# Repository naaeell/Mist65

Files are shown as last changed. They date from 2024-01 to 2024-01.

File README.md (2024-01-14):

# Mist65 ⌨✨

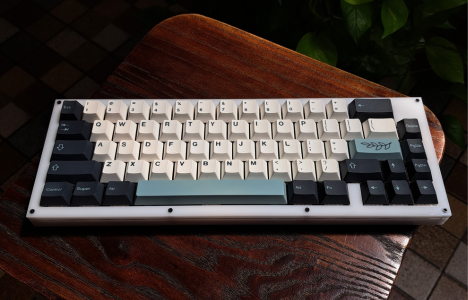
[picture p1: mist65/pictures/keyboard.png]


Introducing Mist65, a 65% custom keyboard inspired by [bakeneko65](https://github.com/kkatano/bakeneko-65). The PCB, aptly named Mist, features a sleek black design reminiscent of nighttime fog. To keep costs reasonable, the ATmega32u4 controller has been replaced with the budget-friendly RP2040 Zero, maintaining similar functionality.

Designed with a 65% layout, Mist65 strikes a balance between compactness and functionality, housing arrow keys for enhanced usability. VIA support ensures seamless keymap customization to tailor the keyboard to your preferences.

For those interested, the Mist65 PCB is available for purchase [here](https://tokopedia.link/6WUgB6gHmGb) (indonesian domestic). If considering group buy or commercial use, kindly adhere to the specified terms.

For more details about materials, instructions, and other information, please visit this [page](https://github.com/naaeell/Mist65/blob/main/mist65/README.md)

## Features 🔮

- No RGB: Clean and distraction-free experience without RGB lighting.
- Drag and Drop Flashing: Streamlined firmware updates with easy drag-and-drop functionality.
- Staggered Design: Comfortable and ergonomic typing experience with a staggered key layout.
- VIA Support: Extensive keymap customization through VIA support. (Keyboard definition required until VIA branch merge)
- QMK Firmware: Reliable and customizable keyboard experience powered by QMK firmware.
- Cost-Effective Components: Budget-friendly design using readily available components.
- Compact 65% Layout: Perfect balance between size and functionality with arrow keys for convenient navigation.
- RP2040 Zero Controller: Cost-effective and performance-maintaining controller readily available in the market.
- Community-Friendly: Vibrant community of keyboard enthusiasts for sharing experiences and modifications.
- Open-Source Design: Creative and adaptable with an open-source design for user contributions and personalization.

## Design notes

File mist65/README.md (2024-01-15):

## Materials

Part list
| Name | Quantity | Description |
| :---| :--- | :--- |
| `1N4148` | `66` | DO-35 (1N4148 or similar).  |
| `RP2040 Zero` | `1` | RP2040 Zero (You can use all models, but first pay attention to the pinout). |
| `Kailh hotswap socket (optional)` | `66` | if you want hotswap features and south facing switches. |
| `Mist65 PCB`  | `1` | Mist65 PCB is available for purchase [here](https://tokopedia.link/6WUgB6gHmGb).|

Case part list

| Name | Quantity | Details|
| :---| :---| :---|
| `Layer 1` | `1` | 3mm thicknes. |
| `Layer 2` | `3` | 3mm thickness. |
| `Layer 3` | `2` | 3mm thickness. |
| `Layer 4` | `1` | 1.5mm thickness. |
| `Layer 5` | `2` | 3mm thickness. |
| `bolts and nuts`| `8` | M2 size with 30mm length.|

*layer 1 is the bottom layer (in order of top).

Tools needed

| Name | Details |
| :---| :---|
| `Solder` |  Any kind of solder is suitable, but I recommend using a pointed or sharp-tipped one. |
| `Tin` | You'll need approximately 4-5 meters of tin wire. |
| `Flux` | Any type of flux is acceptable, but avoid overusing it.  |
| `Tweezers` | Opt for tweezers with a hooked shape. |
| `Nail clippers` | Any type with flat surfaces will work. |

## Let's start building

Firstly, prepare the necessary tools and materials. I will provide you with some tips and tricks. I recommend a soldering temperature of 300 to 350 degrees Celsius; please note that high temperatures can damage the PCB traces. Additionally, the soldering tip may quickly turn black. Each time you solder, ensure to clean the soldering tip thoroughly to prevent residue from sticking to the soldered joints later.

The use of nail clippers instead of cutting pliers is for precision, allowing you to trim component legs more neatly. Before soldering, apply an adequate amount of flux to the PCB. Applying too much flux can complicate cleaning later. Once everything is ready, test-fit the components in place, ensuring they match the silk screen markings on the PCB. Trim any excess component legs promptly; although it may take time, patience is crucial for satisfactory results.

Afterward, solder the components one by one, using tweezers to position them accurately. If a component is tilted, you can correct it with tweezers, but be cautious as this process involves melting the tin and adjusting the component's position. For the microcontroller, there is a ">" sign indicating pin 0 on the rp2040 zero; refer to the picture [below](https://github.com/naaeell/Mist65/blob/main/mist65/pictures/20240113_094051.jpg) for the microcontroller's position. Before soldering, verify that the component placement is correct to achieve neat soldering results.

Begin soldering slowly, ensuring not to melt too much tin; excessive tin can result in poor solder joints. Once all components are soldered, clean the PCB with isopropyl alcohol or contact cleaner.

## Flashing Firmware

- Flash the RPI2040 Zero by pressing and holding the boot button while plugging in the USB until it's detected on the computer as a new drive.

- Drag and drop or copy and paste the file with the .uf2 extension onto the drive. Wait until the keyboard is detected.

#### Unfortunately, the VIA support hasn't been merged into the branch yet. However, to use it, follow these additional steps:

- Visit [https://usevia.app/](https://usevia.app/) and navigate to the gear icon, then enable the "Show Design Tab" option.
- Once active, open the brush icon next to the gear. Click "Load" on the "Load Draft Definition" menu and input the via.json file located in the firmware folder.
- Return to the configuration menu, click on "Device Authorization," and your keyboard will appear, ready to use.

Choose "Mist65_via.uf2" for VIA support or "Mist65_default.uf2" for the default keymap without VIA support.

Create a new keymap tutorial soon!

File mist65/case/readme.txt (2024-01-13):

layer 1 milky white acrylic 3mm x 1
layer 2 milky white acrylic 3mm x 3
layer 3 milk white acrylic 3mm x 2
layer 4 clear acrylic 1.5mm x 2
layer 5 milky white acrylic 3mm x 3

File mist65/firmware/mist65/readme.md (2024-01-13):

# sixtyfive

sixtyfive

*A short description of the keyboard/project*

* Keyboard Maintainer: [naaeell](https://github.com/naaeell)
* Hardware Supported: *The PCBs, controllers supported*
* Hardware Availability: *Links to where you can find this hardware*

Make example for this keyboard (after setting up your build environment):

    make sixtyfive:default

Flashing example for this keyboard:

    make sixtyfive:default:flash

See the [build environment setup](https://docs.qmk.fm/#/getting_started_build_tools) and the [make instructions](https://docs.qmk.fm/#/getting_started_make_guide) for more information. Brand new to QMK? Start with our [Complete Newbs Guide](https://docs.qmk.fm/#/newbs).

## Bootloader

Enter the bootloader in 3 ways:

* **Bootmagic reset**: Hold down the key at (0,0) in the matrix (usually the top left key or Escape) and plug in the keyboard
* **Physical reset button**: Briefly press the button on the back of the PCB - some may have pads you must short instead
* **Keycode in layout**: Press the key mapped to `QK_BOOT` if it is available

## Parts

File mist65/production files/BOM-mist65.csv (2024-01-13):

Comment | Designator | Footprint | LCSC
1N4148 | D1,D10,D11,D12,D13,D14,D15,D16,D17,D18,D19,D2,D20,D21,D22,D23,D24,D25,D26,D27,D28,D29,D3,D30,D31,D32,D33,D34,D35,D36,D37,D38,D39,D4,D40,D41,D42,D43,D44,D45,D46,D47,D48,D49,D5,D50,D51,D52,D53,D54,D55,D56,D57,D58,D59,D6,D60,D61,D62,D63,D64,D65,D66,D7,D8,D9 | D_DO-35_SOD27_P7.62mm_Horizontal | C81598
1u | SW53 | Kailh_socket_MX_optional
1u | SW25 | Kailh_socket_MX_optional
1u | SW16 | Kailh_socket_MX_optional
1u | SW21 | Kailh_socket_MX_optional
1u | SW37 | Kailh_socket_MX_optional
1u | SW5 | Kailh_socket_MX_optional
1u | SW33 | Kailh_socket_MX_optional
1u | SW13 | Kailh_socket_MX_optional
1u | SW10 | Kailh_socket_MX_optional
1.25u | SW63 | Kailh_socket_MX_optional
1u | SW18 | Kailh_socket_MX_optional
1u | SW52 | Kailh_socket_MX_optional
1u | SW56 | Kailh_socket_MX_optional
1u | SW45 | Kailh_socket_MX_optional
1u | SW43 | Kailh_socket_MX_optional
1.25u | SW62 | Kailh_socket_MX_optional
1u | SW29 | Kailh_socket_MX
1u | SW36 | Kailh_socket_MX_optional
2.25u | SW42 | Kailh_socket_MX_optional
1u | SW27 | Kailh_socket_MX_optional
1u | SW2 | Kailh_socket_MX_optional
1u | SW35 | Kailh_socket_MX_optional
1u | SW31 | Kailh_socket_MX_optional
MX_stab | S4 | STAB_MX_2.25u
1u | SW41 | Kailh_socket_MX_optional
1u | SW49 | Kailh_socket_MX_optional
1u | SW12 | Kailh_socket_MX_optional
1u | SW54 | Kailh_socket_MX_optional
1.5u | SW28 | Kailh_socket_MX_optional
1u | SW17 | Kailh_socket_MX_optional
1u | SW24 | Kailh_socket_MX_optional
1u | SW64 | Kailh_socket_MX_optional
MX_stab | S2 | STAB_MX_2u
1.5u | SW15 | Kailh_socket_MX_optional
1u | SW66 | Kailh_socket_MX_optional
1u | SW65 | Kailh_socket_MX_optional
2.25u | SW44 | Kailh_socket_MX_optional
1u | SW26 | Kailh_socket_MX_optional
1u | SW19 | Kailh_socket_MX_optional
MX_stab | S3 | STAB_MX_2.25u
1u | SW6 | Kailh_socket_MX_optional
1u | SW3 | Kailh_socket_MX_optional
1u | SW48 | Kailh_socket_MX_optional
1u | SW32 | Kailh_socket_MX_optional
1u | SW20 | Kailh_socket_MX_optional
6.25u | SW61 | Kailh_socket_MX_optional
1u | SW57 | Kailh_socket_MX_optional
2u | SW14 | Kailh_socket_MX_optional
1.25u | SW59 | Kailh_socket_MX_optional
1u | SW34 | Kailh_socket_MX_optional
1.75u | SW30 | Kailh_socket_MX_optional
1u | SW23 | Kailh_socket_MX_optional
1u | SW11 | Kailh_socket_MX_optional
1u | SW1 | Kailh_socket_MX_optional
1.75u | SW55 | Kailh_socket_MX_optional
1u | SW39 | Kailh_socket_MX_optional
1u | SW40 | Kailh_socket_MX_optional
1u | SW22 | Kailh_socket_MX_optional
1u | SW9 | Kailh_socket_MX_optional
1u | SW50 | Kailh_socket_MX_optional
1u | SW4 | Kailh_socket_MX_optional
1.25u | SW58 | Kailh_socket_MX_optional
1u | SW46 | Kailh_socket_MX_optional
MX_stab | S1 | STAB_MX_6.25u
1u | SW38 | Kailh_socket_MX_optional
1u | SW8 | Kailh_socket_MX_optional
1u | SW51 | Kailh_socket_MX_optional
1.25u | SW60 | Kailh_socket_MX_optional
1u | SW7 | Kailh_socket_MX_optional
1u | SW47 | Kailh_socket_MX_optional
RP2040-Zero | RZ1 | RP2040-Zero

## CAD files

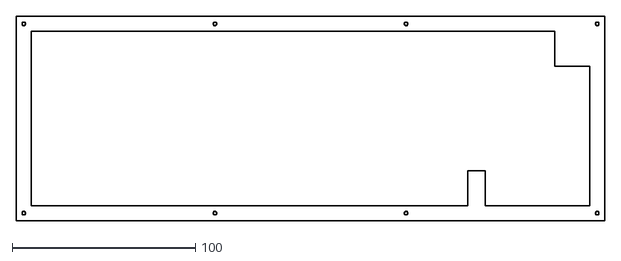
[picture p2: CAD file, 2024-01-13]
mist65/case/layer 5.dxf
320.9 x 111.3

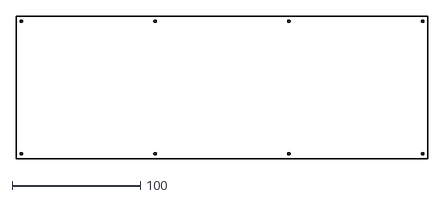
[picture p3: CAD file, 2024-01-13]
mist65/case/layer 1.dxf
320.9 x 111.3

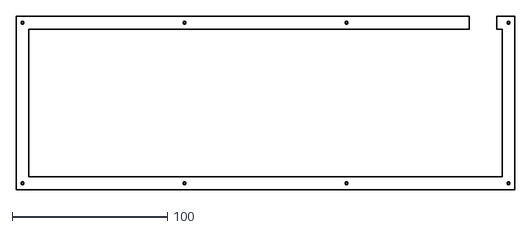
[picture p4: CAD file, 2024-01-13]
mist65/case/layer 2.dxf
320.9 x 111.3

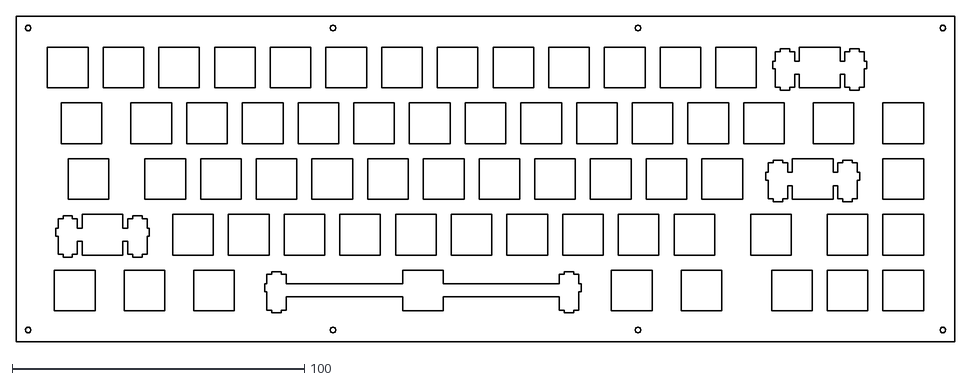
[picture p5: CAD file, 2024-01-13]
mist65/case/layer 4.dxf
320.9 x 111.3

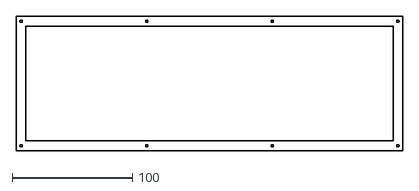
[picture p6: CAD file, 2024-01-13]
mist65/case/layer 3.dxf
320.9 x 111.3

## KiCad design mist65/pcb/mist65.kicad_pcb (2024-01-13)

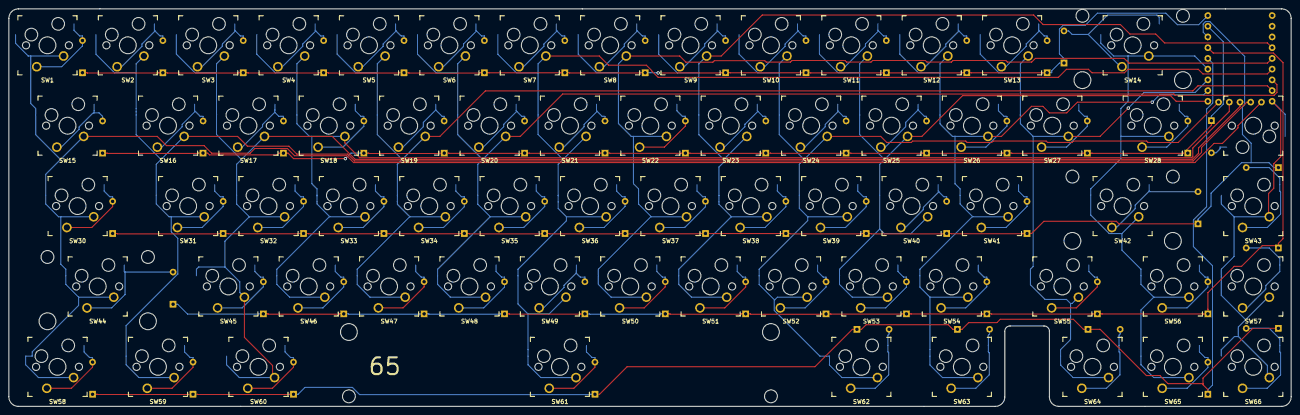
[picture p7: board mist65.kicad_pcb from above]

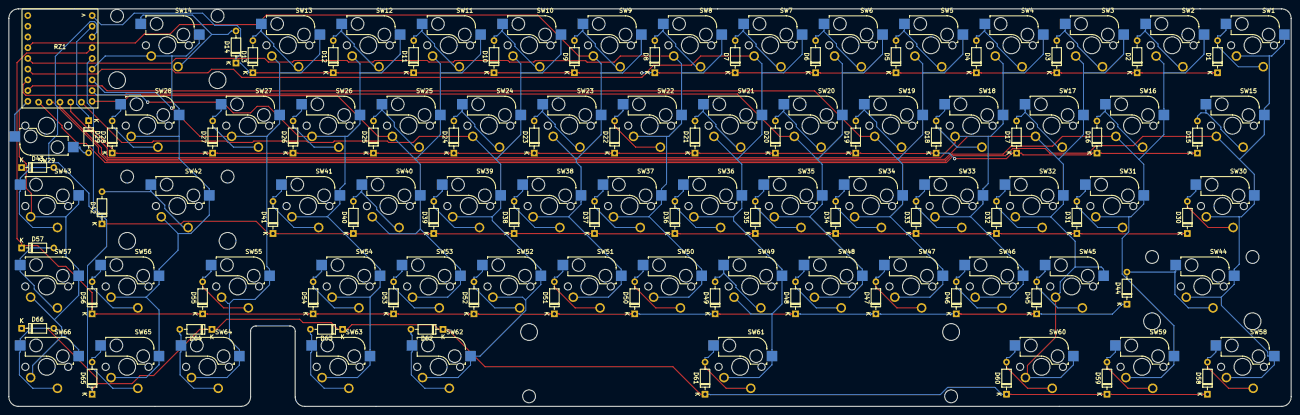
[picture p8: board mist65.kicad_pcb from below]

Board: 2 copper layers, 303.9 x 94.2 mm, 137 parts (67 on the bottom side), 86 nets.

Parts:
D1, D2, D3, D4, D5, D6, D7, D8, D9, D10, D11, D12, D13, D14, D15, D16, D17, D18, D19, D20, D21, D22, D23, D24, D25, D26, D27, D28, D29, D30, D31, D32, D33, D34, D35, D36, D37, D38, D39, D40, D41, D42, D43, D44, D45, D46, D47, D48, D49, D50, D51, D52, D53, D54, D55, D56, D57, D58, D59, D60, D61, D62, D63, D64, D65, D66: 1N4148; D_DO-35_SOD27_P7.62mm_Horizontal
RZ1: RP2040-Zero
S1: MX_stab; STAB_MX_6.25u
S2: MX_stab; STAB_MX_2u
S3, S4: MX_stab; STAB_MX_2.25u
SW1, SW2, SW3, SW4, SW5, SW6, SW7, SW8, SW9, SW10, SW11, SW12, SW13, SW16, SW17, SW18, SW19, SW20, SW21, SW22, SW23, SW24, SW25, SW26, SW27, SW31, SW32, SW33, SW34, SW35, SW36, SW37, SW38, SW39, SW40, SW41, SW43, SW45, SW46, SW47, SW48, SW49, SW50, SW51, SW52, SW53, SW54, SW56, SW57, SW64, SW65, SW66: 1u; Kailh_socket_MX_optional
SW14: 2u; Kailh_socket_MX_optional
SW15, SW28: 1.5u; Kailh_socket_MX_optional
SW29: 1u; Kailh_socket_MX
SW30, SW55: 1.75u; Kailh_socket_MX_optional
SW42, SW44: 2.25u; Kailh_socket_MX_optional
SW58, SW59, SW60, SW62, SW63: 1.25u; Kailh_socket_MX_optional
SW61: 6.25u; Kailh_socket_MX_optional

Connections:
COL0: RZ1.14 (GP13), SW1.2 (B), SW15.2 (B), SW30.2 (B), SW44.2 (B), SW58.2 (B)
COL1: RZ1.13 (GP12), SW2.2 (B), SW16.2 (B), SW31.2 (B), SW59.2 (B)
COL2: RZ1.12 (GP11), SW3.2 (B), SW17.2 (B), SW32.2 (B), SW45.2 (B), SW60.2 (B)
COL3: RZ1.11 (GP10), SW4.2 (B), SW18.2 (B), SW33.2 (B), SW46.2 (B)
COL4: RZ1.16 (GP15), SW5.2 (B), SW19.2 (B), SW34.2 (B), SW47.2 (B)
COL5: RZ1.17 (GP26), SW6.2 (B), SW20.2 (B), SW35.2 (B), SW48.2 (B)
COL6: RZ1.18 (GP27), SW7.2 (B), SW21.2 (B), SW36.2 (B), SW49.2 (B), SW61.2 (B)
COL7: RZ1.19 (GP28), SW8.2 (B), SW22.2 (B), SW37.2 (B), SW50.2 (B)
COL8: RZ1.20 (GP29), SW9.2 (B), SW23.2 (B), SW38.2 (B), SW51.2 (B)
COL9: RZ1.10 (GP9), SW10.2 (B), SW24.2 (B), SW39.2 (B), SW52.2 (B), SW62.2 (B)
COL10: RZ1.9 (GP8), SW11.2 (B), SW25.2 (B), SW40.2 (B), SW53.2 (B)
COL11: RZ1.8 (GP7), SW12.2 (B), SW26.2 (B), SW41.2 (B), SW54.2 (B), SW63.2 (B)
COL12: RZ1.7 (GP6), SW13.2 (B), SW27.2 (B), SW55.2 (B), SW64.2 (B)
COL13: RZ1.6 (GP5), SW14.2 (B), SW28.2 (B), SW42.2 (B), SW56.2 (B), SW65.2 (B)
COL14: RZ1.15 (GP14), SW29.2 (B), SW43.2 (B), SW57.2 (B), SW66.2 (B)
unnamed: D1.2 (A), SW1.1 (A)
unnamed: D2.2 (A), SW2.1 (A)
unnamed: D3.2 (A), SW3.1 (A)
unnamed: D4.2 (A), SW4.1 (A)
unnamed: D5.2 (A), SW5.1 (A)
unnamed: D6.2 (A), SW6.1 (A)
unnamed: D7.2 (A), SW7.1 (A)
unnamed: D8.2 (A), SW8.1 (A)
unnamed: D9.2 (A), SW9.1 (A)
unnamed: D10.2 (A), SW10.1 (A)
unnamed: D11.2 (A), SW11.1 (A)
unnamed: D12.2 (A), SW12.1 (A)
unnamed: D13.2 (A), SW13.1 (A)
unnamed: D14.2 (A), SW14.1 (A)
unnamed: D15.2 (A), SW15.1 (A)
unnamed: D16.2 (A), SW16.1 (A)
unnamed: D17.2 (A), SW17.1 (A)
unnamed: D18.2 (A), SW18.1 (A)
unnamed: D19.2 (A), SW19.1 (A)
unnamed: D20.2 (A), SW20.1 (A)
unnamed: D21.2 (A), SW21.1 (A)
unnamed: D22.2 (A), SW22.1 (A)
unnamed: D23.2 (A), SW23.1 (A)
unnamed: D24.2 (A), SW24.1 (A)
unnamed: D25.2 (A), SW25.1 (A)
unnamed: D26.2 (A), SW26.1 (A)
unnamed: D27.2 (A), SW27.1 (A)
unnamed: D28.2 (A), SW28.1 (A)
unnamed: D29.2 (A), SW29.1 (A)
unnamed: D30.2 (A), SW30.1 (A)
unnamed: D31.2 (A), SW31.1 (A)
unnamed: D32.2 (A), SW32.1 (A)
unnamed: D33.2 (A), SW33.1 (A)
unnamed: D34.2 (A), SW34.1 (A)
unnamed: D35.2 (A), SW35.1 (A)
unnamed: D36.2 (A), SW36.1 (A)
unnamed: D37.2 (A), SW37.1 (A)
unnamed: D38.2 (A), SW38.1 (A)
unnamed: D39.2 (A), SW39.1 (A)
unnamed: D40.2 (A), SW40.1 (A)
unnamed: D41.2 (A), SW41.1 (A)
unnamed: D42.2 (A), SW42.1 (A)
unnamed: D43.2 (A), SW43.1 (A)
unnamed: D44.2 (A), SW44.1 (A)
unnamed: D45.2 (A), SW45.1 (A)
unnamed: D46.2 (A), SW46.1 (A)
unnamed: D47.2 (A), SW47.1 (A)
unnamed: D48.2 (A), SW48.1 (A)
unnamed: D49.2 (A), SW49.1 (A)
unnamed: D50.2 (A), SW50.1 (A)
unnamed: D51.2 (A), SW51.1 (A)
unnamed: D52.2 (A), SW52.1 (A)
unnamed: D53.2 (A), SW53.1 (A)
unnamed: D54.2 (A), SW54.1 (A)
unnamed: D55.2 (A), SW55.1 (A)
unnamed: D56.2 (A), SW56.1 (A)
unnamed: D57.2 (A), SW57.1 (A)
unnamed: D58.2 (A), SW58.1 (A)
unnamed: D59.2 (A), SW59.1 (A)
unnamed: D60.2 (A), SW60.1 (A)
unnamed: D61.2 (A), SW61.1 (A)
unnamed: D62.2 (A), SW62.1 (A)
unnamed: D63.2 (A), SW63.1 (A)
unnamed: D64.2 (A), SW64.1 (A)
unnamed: D65.2 (A), SW65.1 (A)
unnamed: D66.2 (A), SW66.1 (A)
ROW0: D1.1 (K), D2.1 (K), D3.1 (K), D4.1 (K), D5.1 (K), D6.1 (K), D7.1 (K), D8.1 (K), D9.1 (K), D10.1 (K), D11.1 (K), D12.1 (K), D13.1 (K), D14.1 (K), RZ1.1 (GP0)
ROW1: D15.1 (K), D16.1 (K), D17.1 (K), D18.1 (K), D19.1 (K), D20.1 (K), D21.1 (K), D22.1 (K), D23.1 (K), D24.1 (K), D25.1 (K), D26.1 (K), D27.1 (K), D28.1 (K), D29.1 (K), RZ1.2 (GP1)
ROW2: D30.1 (K), D31.1 (K), D32.1 (K), D33.1 (K), D34.1 (K), D35.1 (K), D36.1 (K), D37.1 (K), D38.1 (K), D39.1 (K), D40.1 (K), D41.1 (K), D42.1 (K), D43.1 (K), RZ1.3 (GP2)
ROW3: D44.1 (K), D45.1 (K), D46.1 (K), D47.1 (K), D48.1 (K), D49.1 (K), D50.1 (K), D51.1 (K), D52.1 (K), D53.1 (K), D54.1 (K), D55.1 (K), D56.1 (K), D57.1 (K), RZ1.4 (GP3)
ROW4: D58.1 (K), D59.1 (K), D60.1 (K), D61.1 (K), D62.1 (K), D63.1 (K), D64.1 (K), D65.1 (K), D66.1 (K), RZ1.5 (GP4)
